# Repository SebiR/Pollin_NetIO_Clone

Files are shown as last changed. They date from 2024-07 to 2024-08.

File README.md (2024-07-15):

# Pollin NetIO Clone
> [!WARNING]  
> The original design is flawed in many ways. If you want to build this design, you should be prepared for some disappointment!
> If you know what you're doing, go ahead. Otherwise you might want to wait for the improved version.

This is a clone of the original Pollin NetIO board.

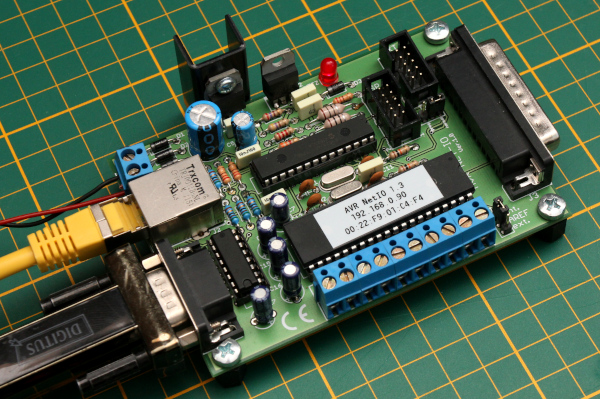
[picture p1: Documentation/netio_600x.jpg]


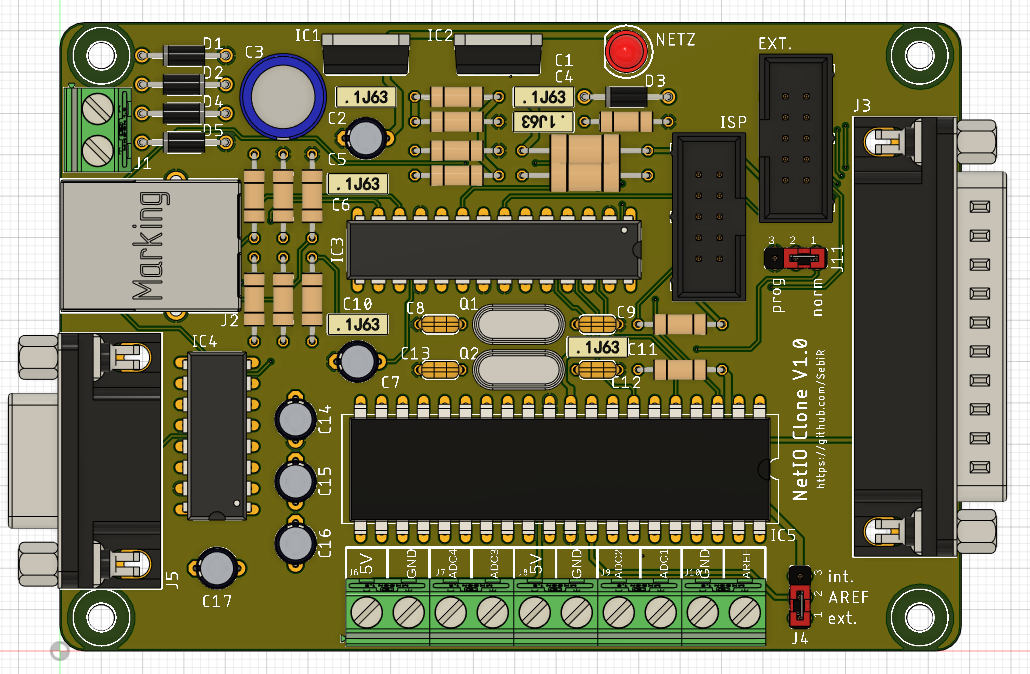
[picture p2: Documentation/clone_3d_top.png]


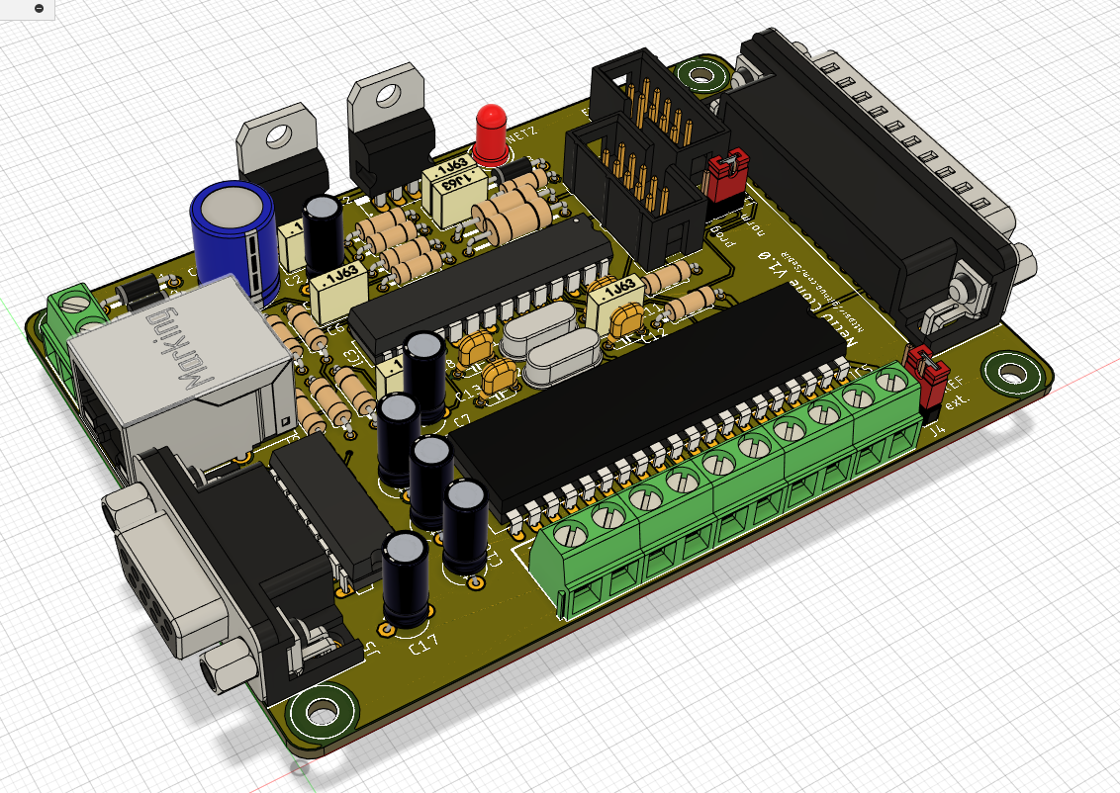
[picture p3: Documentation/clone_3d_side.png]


## Versions
### Original

* As identical as possible to the original
* outline and placement of the components as close as possible
* Assembly plan of the original works

### Improved (tbd)
* Mechanical identical
* Added capacitors and diodes for stability
* placement of the components as close to the original as possible

Things to improve:
* ATmega32 to 3V3? -> Consider compability of extensions
* More capacitors for the ENC28J60
* Diode + capacitors for the LM317
* Connect RS232 handshake lines -> Arduino bootloader compatible

## Software
The original Pollin Netserver 1.03 (provided on a CD) is in /Software/Netserver.zip

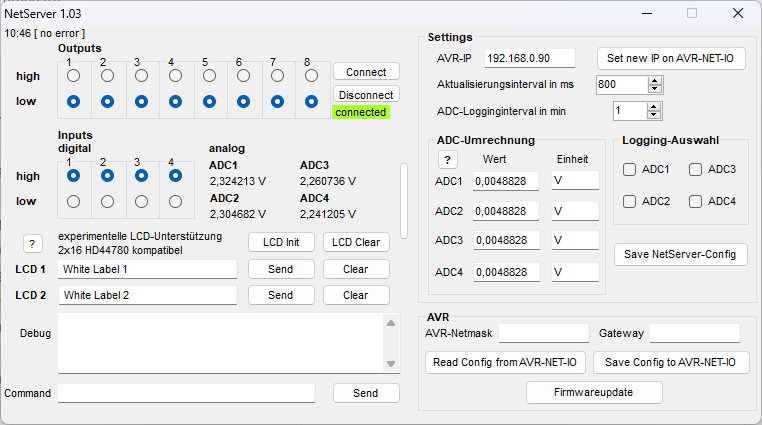
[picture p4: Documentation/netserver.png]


It works just fine with Windows 11.

## Firmware
The original firmware is included.

The MAC address is stored in the EEPROM and can be modified in the .eep file:


So this is MAC address 00:22:F9:01:C4:F4

## Resources
EEPROM Structure: https://www.mikrocontroller.net/topic/112937#1016995

Hardware improvements: https://community.symcon.de/t/p-llins-avr-net-io-langzeitstabilitaet-des-lan-chips/24317/12

General: https://www.mikrocontroller.net/articles/AVR_Net-IO_Bausatz_von_Pollin

## Disclaimer
> [!CAUTION]
> This project was created to archive and preserve the NetIO PCB. Pollin owns all the rights to this design.
> There's no copyright infringement intended, please contact me for removal.

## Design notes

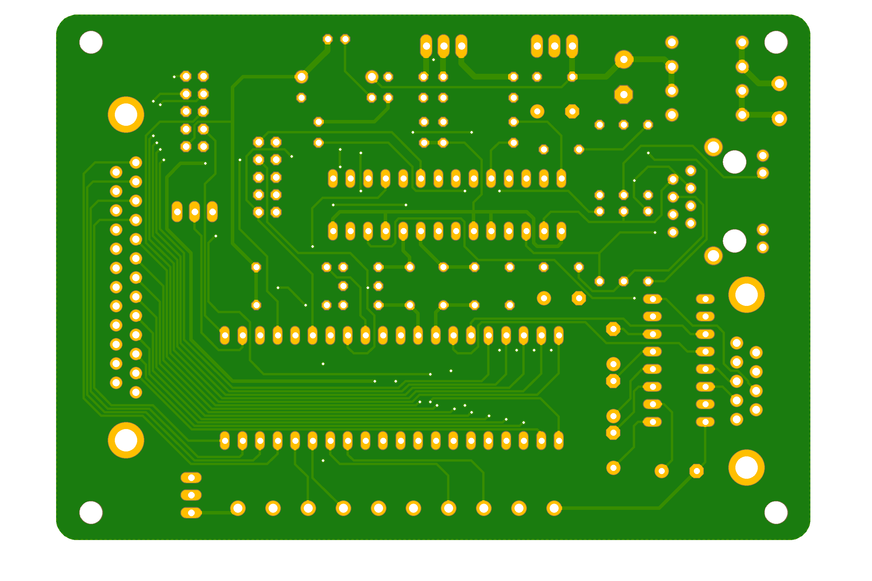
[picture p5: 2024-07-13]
Documentation/Pollin_NetIO_Clone_bot.png

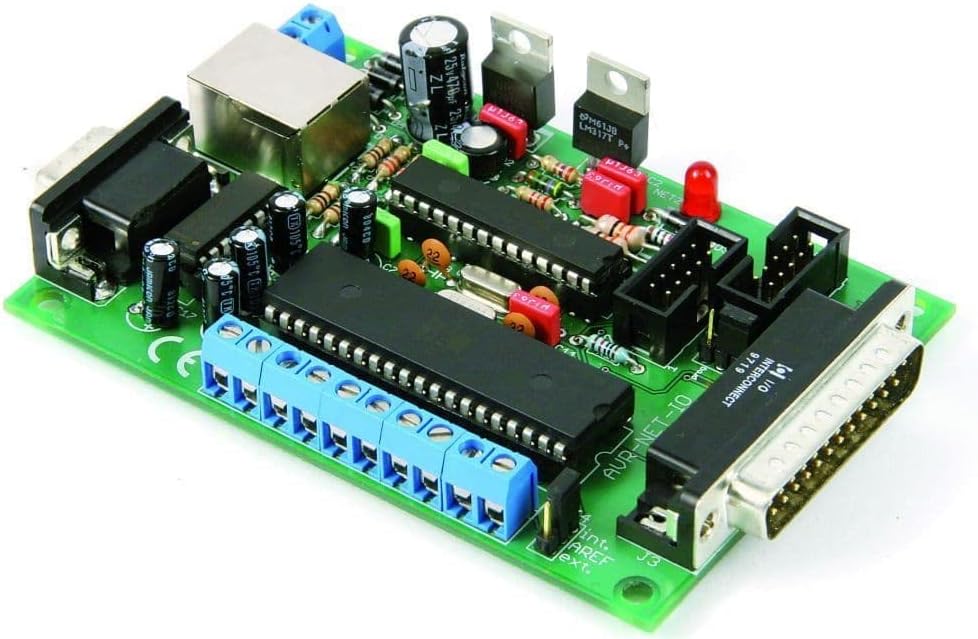
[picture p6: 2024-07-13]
Documentation/netio_original.jpg

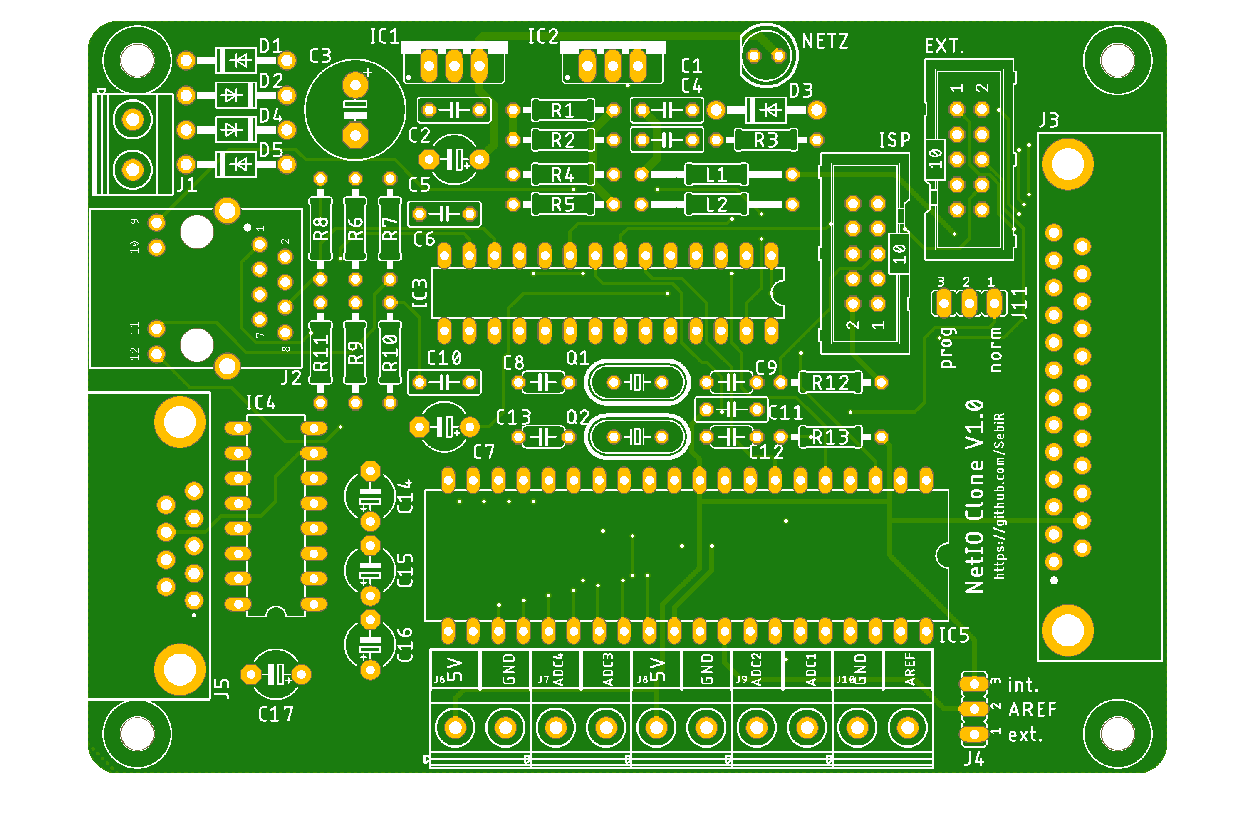
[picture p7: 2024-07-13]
Documentation/Pollin_NetIO_Clone_top.png

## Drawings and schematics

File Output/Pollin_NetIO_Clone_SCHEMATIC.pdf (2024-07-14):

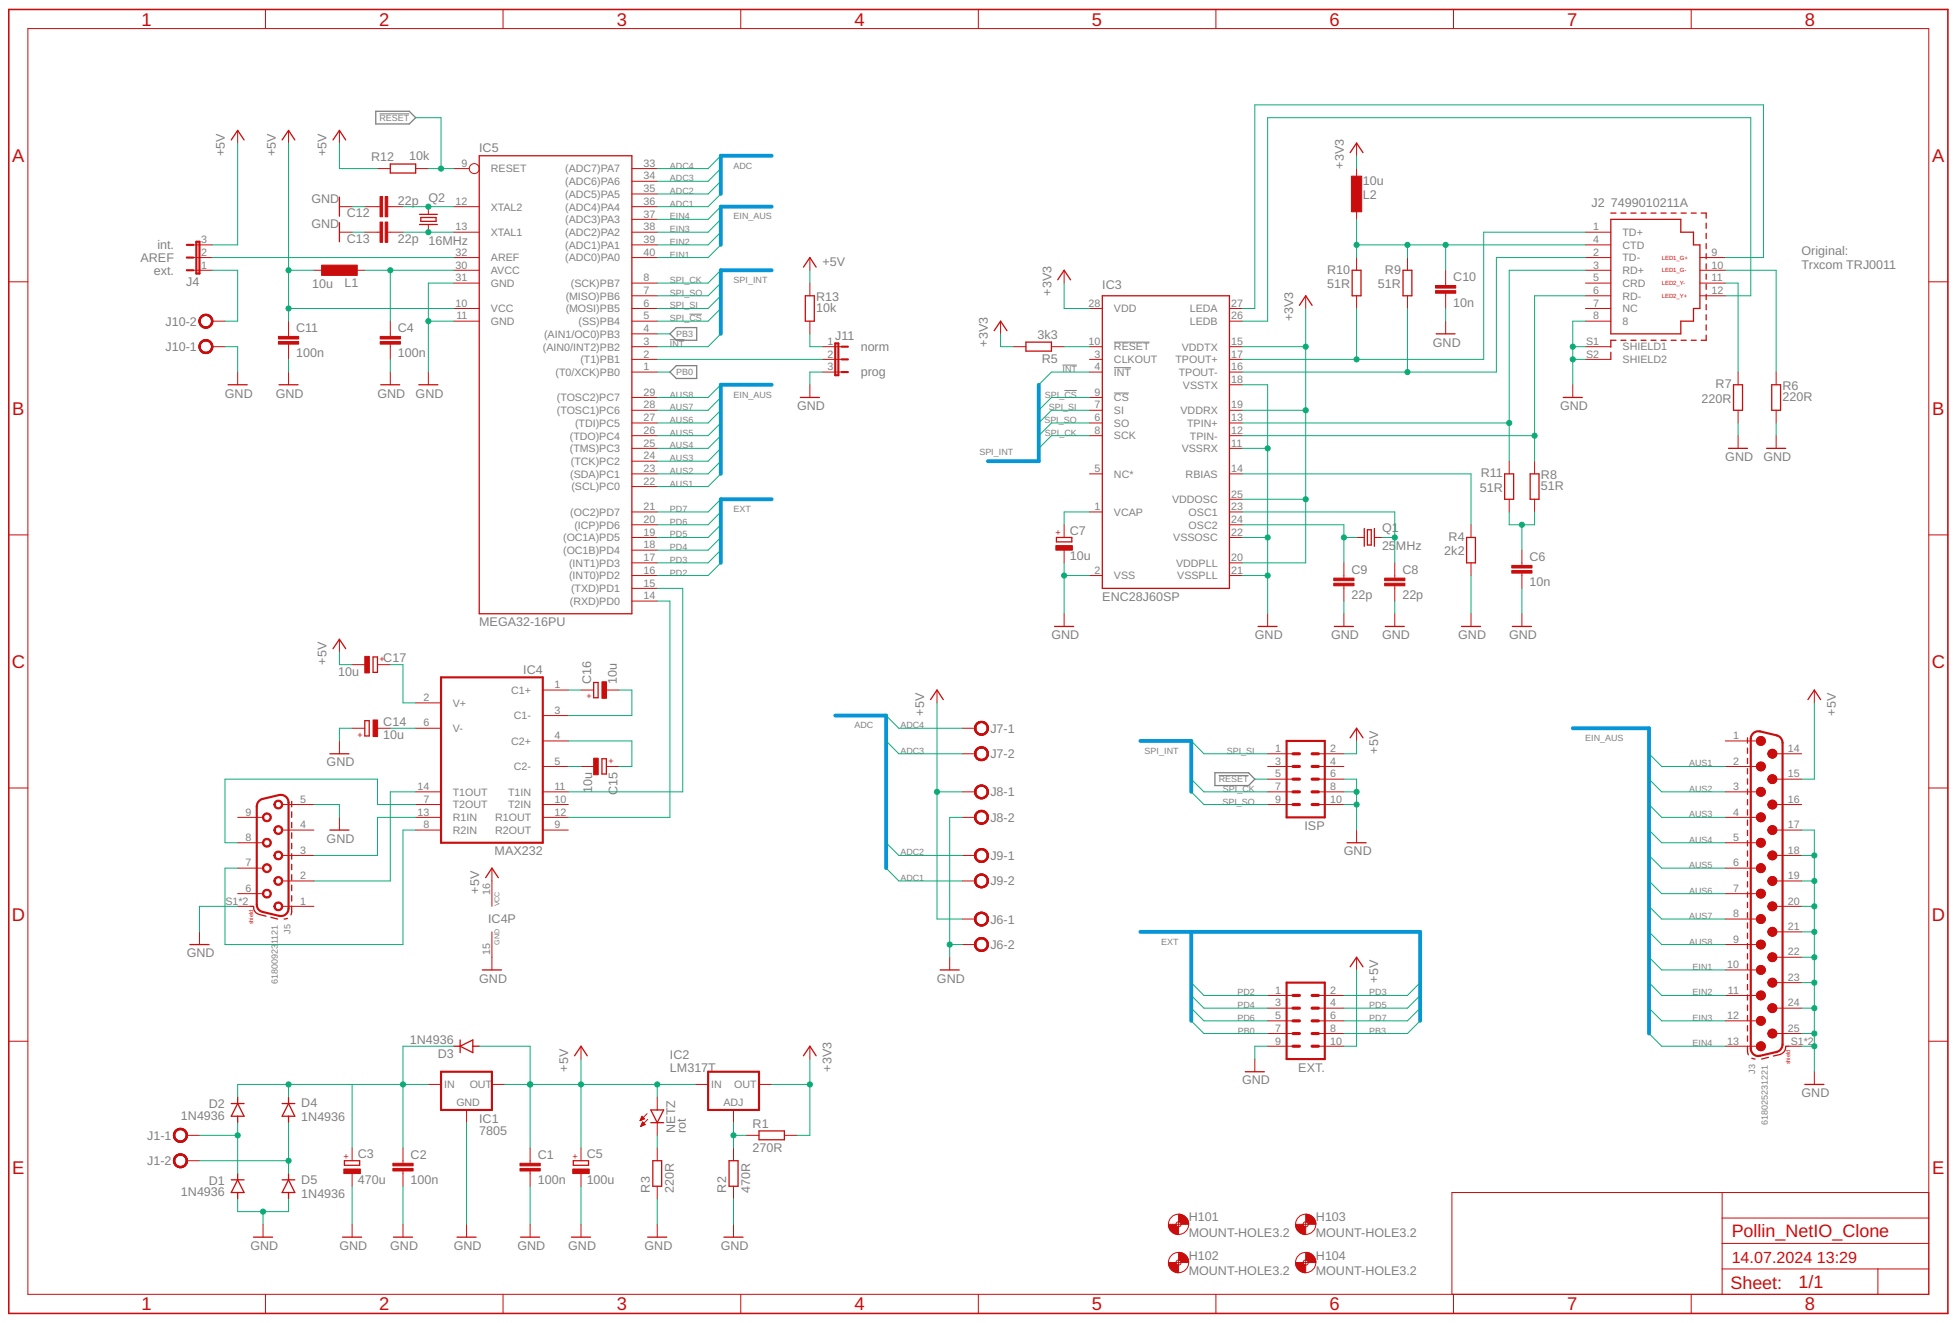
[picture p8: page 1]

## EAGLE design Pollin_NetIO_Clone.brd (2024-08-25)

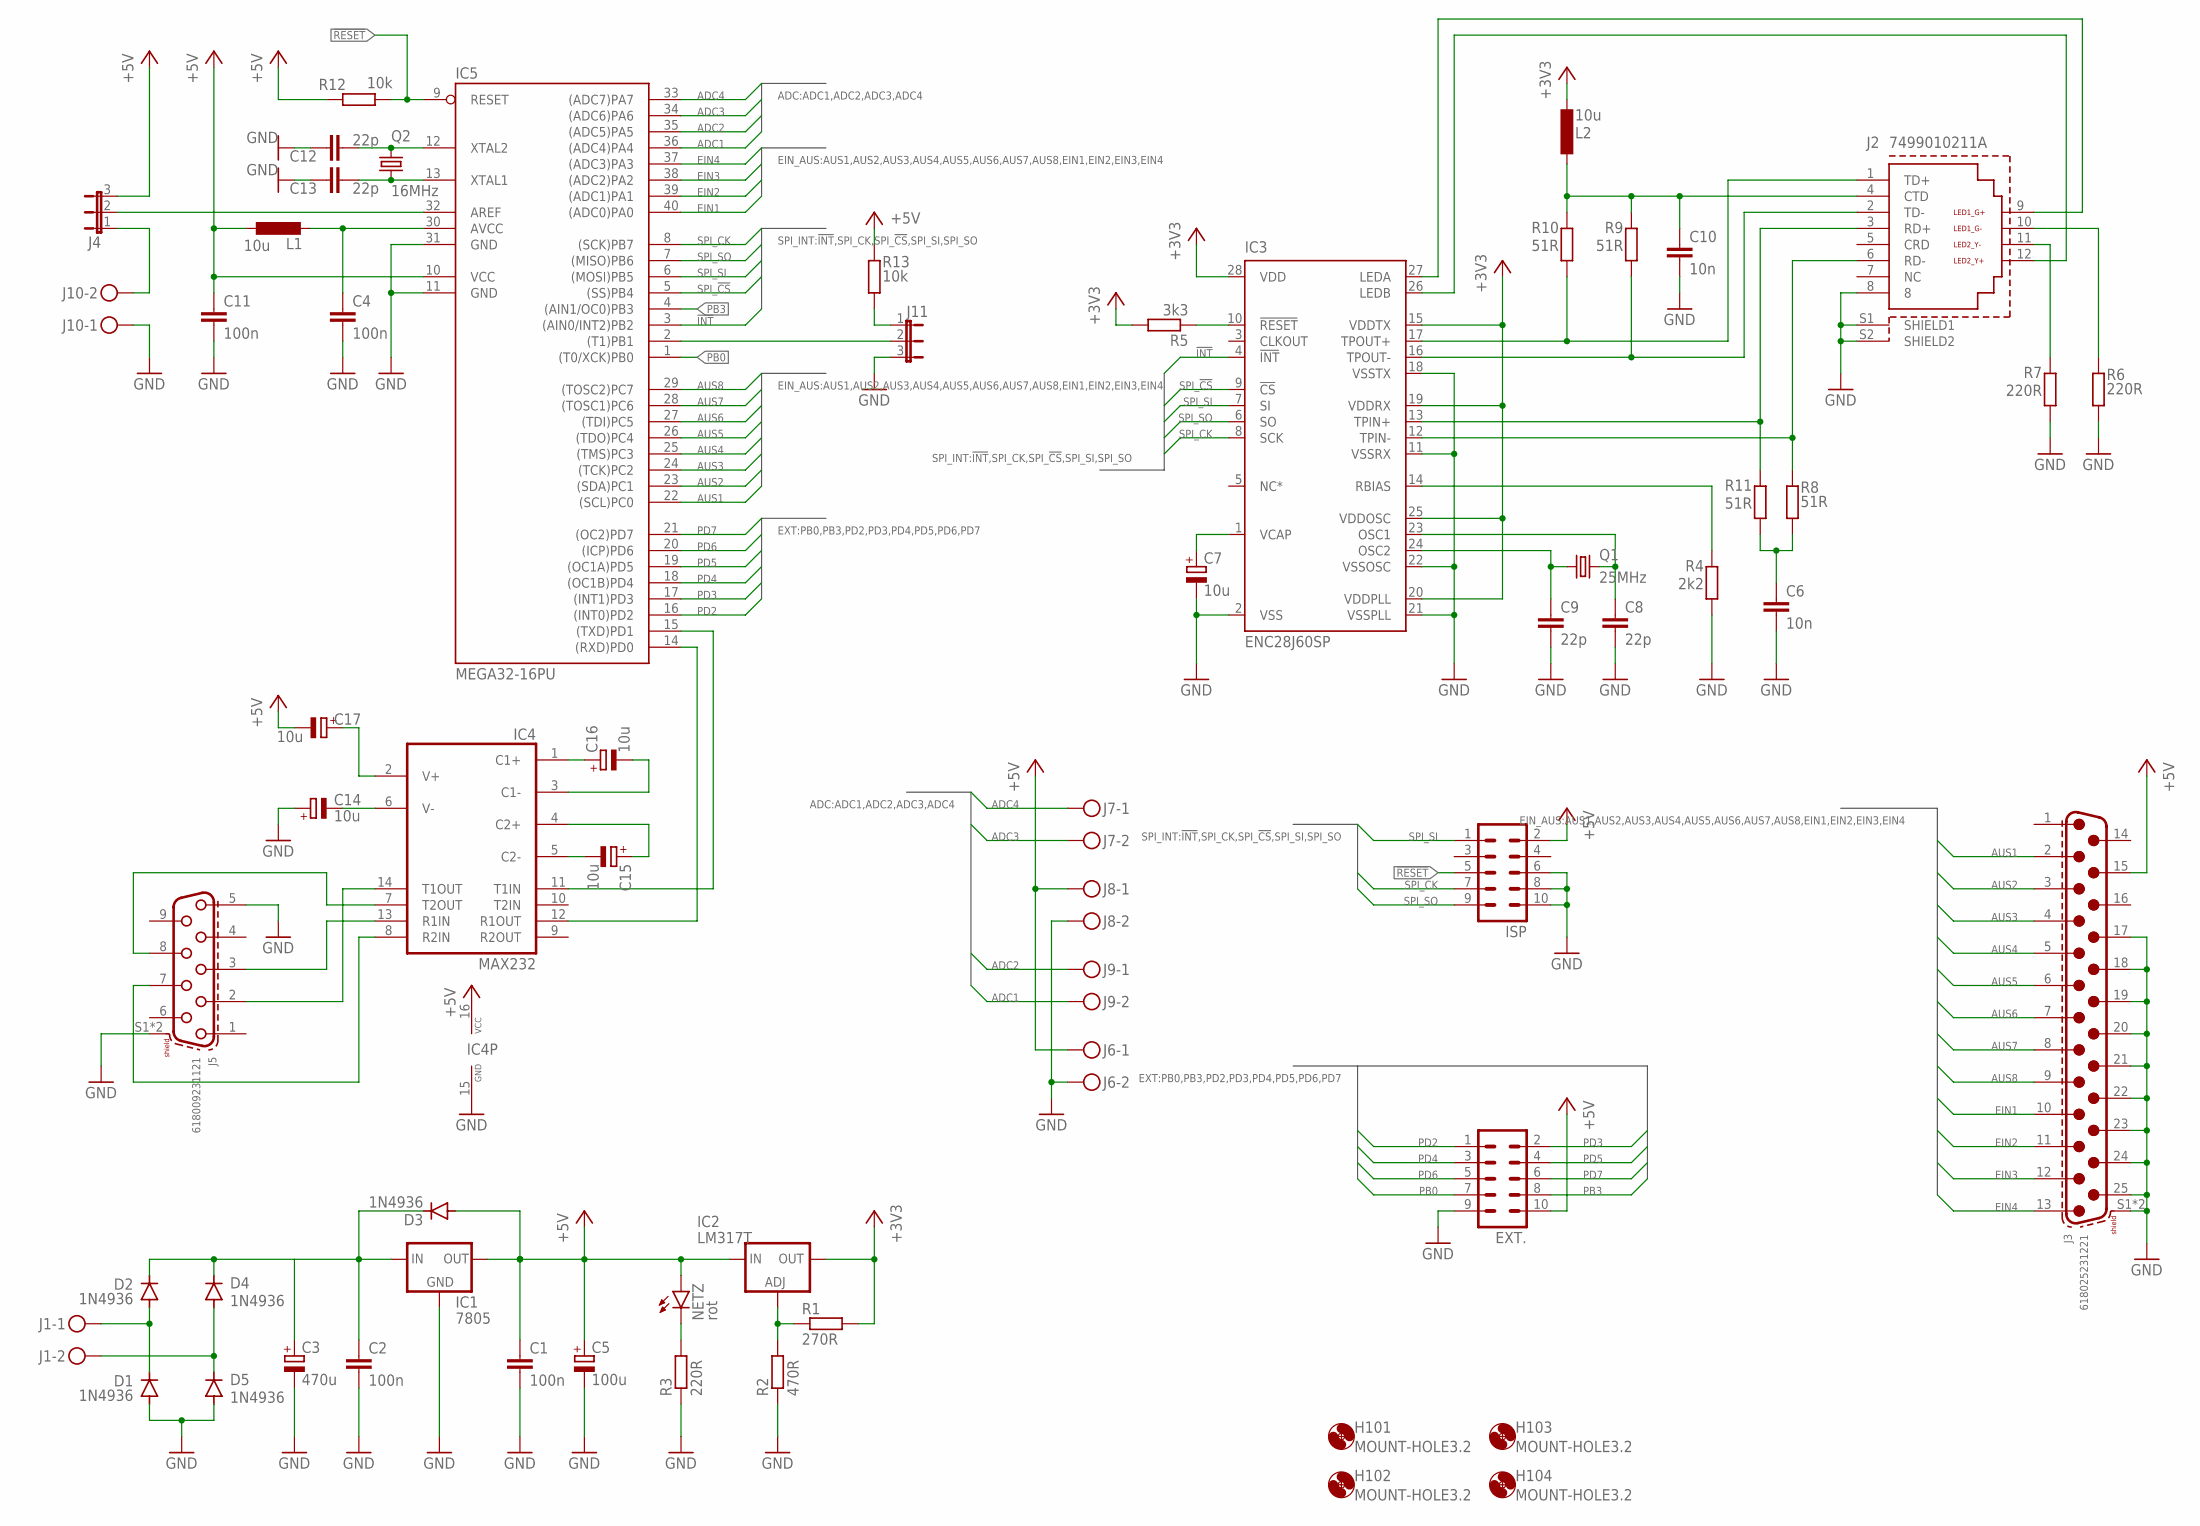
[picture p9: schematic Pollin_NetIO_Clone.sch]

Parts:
C1, C2, C4, C11: 100n; C050-025X075
C3: 470u; E5-10,5
C5: 100u; E5-5
C6, C10: 10n; C050-025X075
C7, C14, C15, C16, C17: 10u; E5-5
C8, C9, C12, C13: 22p; C050-024X044
D1, D2, D3, D4, D5: 1N4936; DO41-10
EXT.: ML10
H101, H102, H103, H104: MOUNT-HOLE3.2; 3,2
IC1: 7805; 78XXS
IC2: LM317T; 317TS
IC3: ENC28J60SP; DIL28-3
IC4: MAX232; DIL16
IC5: MEGA32-16PU; DIL40
ISP: ML10
J1, J6, J7, J8, J9, J10: MKDSN1,5/2-5,08
J2: 7499010211A
J3: 618025231221
J4, J11: JP2E; JP2
J5: 618009231121
L1, L2: 10u; 0207/15
NETZ: rot; LED5MM
Q1: 25MHz; HC49/S
Q2: 16MHz; HC49/S
R1: 270R; 0207/10
R2: 470R; 0207/10
R3, R6, R7: 220R; 0207/10
R4: 2k2; 0207/10
R5: 3k3; 0207/10
R8, R9, R10, R11: 51R; 0207/10
R12, R13: 10k; 0207/10

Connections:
!INT: IC3.4 (!INT), IC5.3 ((AIN0/INT2)PB2)
!RESET: IC5.9 (RESET), ISP.5, R12.2
+3V3: IC2.2 (OUT), IC3.15 (VDDTX), IC3.19 (VDDRX), IC3.20 (VDDPLL), IC3.25 (VDDOSC), IC3.28 (VDD), L2.2, R1.2, R5.2
+5V: C1.1, C5.+, C11.1, C17.-, D3.A, EXT..10, IC1.OUT, IC2.3 (IN), IC4.16 (VCC), IC5.10 (VCC), ISP.2, J3.15, J4.3, J6.1, J8.1, L1.1, NETZ.A, R12.1, R13.2
ADC1: IC5.36 ((ADC4)PA4), J9.2
ADC2: IC5.35 ((ADC5)PA5), J9.1
ADC3: IC5.34 ((ADC6)PA6), J7.2
ADC4: IC5.33 ((ADC7)PA7), J7.1
AREF: IC5.32 (AREF), J4.2
AREF_EXT: J4.1, J10.2
AUS1: IC5.22 ((SCL)PC0), J3.2
AUS2: IC5.23 ((SDA)PC1), J3.3
AUS3: IC5.24 ((TCK)PC2), J3.4
AUS4: IC5.25 ((TMS)PC3), J3.5
AUS5: IC5.26 ((TDO)PC4), J3.6
AUS6: IC5.27 ((TDI)PC5), J3.7
AUS7: IC5.28 ((TOSC1)PC6), J3.8
AUS8: IC5.29 ((TOSC2)PC7), J3.9
AVCC: C4.1, IC5.30 (AVCC), L1.2
EIN1: IC5.40 ((ADC0)PA0), J3.10
EIN2: IC5.39 ((ADC1)PA1), J3.11
EIN3: IC5.38 ((ADC2)PA2), J3.12
EIN4: IC5.37 ((ADC3)PA3), J3.13
GND: C1.2, C2.2, C3.-, C4.2, C5.-, C6.2, C7.-, C8.2, C9.2, C10.2, C11.2, C12.1, C13.1, C14.+, D1.A, D5.A, EXT..9, IC1.GND, IC3.2 (VSS), IC3.11 (VSSRX), IC3.18 (VSSTX), IC3.21 (VSSPLL), IC3.22 (VSSOSC), IC4.15 (GND), IC5.11 (GND), IC5.31 (GND), ISP.6, ISP.8, ISP.10, J2.8, J2.S1 (SHIELD1), J2.S2 (SHIELD2), J3.17, J3.18, J3.19, J3.20, J3.21, J3.22, J3.23, J3.24, J3.25, J3.S1 (SHIELD), J3.S2 (SHIELD), J5.5, J5.S1 (SHIELD), J5.S2 (SHIELD), J6.2, J8.2, J10.1, J11.3, R2.1, R3.1, R4.1, R6.1, R7.1
LEDA: IC3.27 (LEDA), J2.9 (LED1_G+)
LEDB: IC3.26 (LEDB), J2.12 (LED2_Y+)
unnamed: C12.2, IC5.12 (XTAL2), Q2.2
unnamed: C13.2, IC5.13 (XTAL1), Q2.1
unnamed: IC5.2 ((T1)PB1), J11.2
unnamed: C8.1, IC3.23 (OSC1), Q1.1
unnamed: C9.1, IC3.24 (OSC2), Q1.2
unnamed: D1.C, D2.A, J1.1
unnamed: D4.A, D5.C, J1.2
unnamed: C2.1, C3.+, D2.C, D3.C, D4.C, IC1.IN
unnamed: NETZ.K (C), R3.2
unnamed: IC3.14 (RBIAS), R4.2
unnamed: IC2.1 (ADJ), R1.1, R2.2
unnamed: IC3.10 (!RESET), R5.1
unnamed: IC3.17 (TPOUT+), J2.1 (TD+), R10.1
unnamed: IC3.16 (TPOUT-), J2.2 (TD-), R9.1
unnamed: IC3.13 (TPIN+), J2.3 (RD+), R11.2
unnamed: IC3.12 (TPIN-), J2.6 (RD-), R8.2
unnamed: C10.1, J2.4 (CTD), L2.1, R9.2, R10.2
unnamed: C6.1, R8.1, R11.1
unnamed: J11.1, R13.1
unnamed: C7.+, IC3.1 (VCAP)
unnamed: C16.+, IC4.1 (C1+)
unnamed: C16.-, IC4.3 (C1-)
unnamed: C15.+, IC4.4 (C2+)
unnamed: C15.-, IC4.5 (C2-)
unnamed: C17.+, IC4.2 (V+)
unnamed: C14.-, IC4.6 (V-)
unnamed: IC4.7 (T2OUT), J5.8
unnamed: IC4.8 (R2IN), J5.7
unnamed: IC4.14 (T1OUT), J5.2
unnamed: IC4.13 (R1IN), J5.3
unnamed: J2.11 (LED2_Y-), R7.2
unnamed: J2.10 (LED1_G-), R6.2
PB0: EXT..7, IC5.1 ((T0/XCK)PB0)
PB3: EXT..8, IC5.4 ((AIN1/OC0)PB3)
PD2: EXT..1, IC5.16 ((INT0)PD2)
PD3: EXT..2, IC5.17 ((INT1)PD3)
PD4: EXT..3, IC5.18 ((OC1B)PD4)
PD5: EXT..4, IC5.19 ((OC1A)PD5)
PD6: EXT..5, IC5.20 ((ICP)PD6)
PD7: EXT..6, IC5.21 ((OC2)PD7)
RXD: IC4.12 (R1OUT), IC5.14 ((RXD)PD0)
SPI_!CS: IC3.9 (!CS), IC5.5 ((SS)PB4)
SPI_CK: IC3.8 (SCK), IC5.8 ((SCK)PB7), ISP.7
SPI_SI: IC3.7 (SI), IC5.6 ((MOSI)PB5), ISP.1
SPI_SO: IC3.6 (SO), IC5.7 ((MISO)PB6), ISP.9
TXD: IC4.11 (T1IN), IC5.15 ((TXD)PD1)

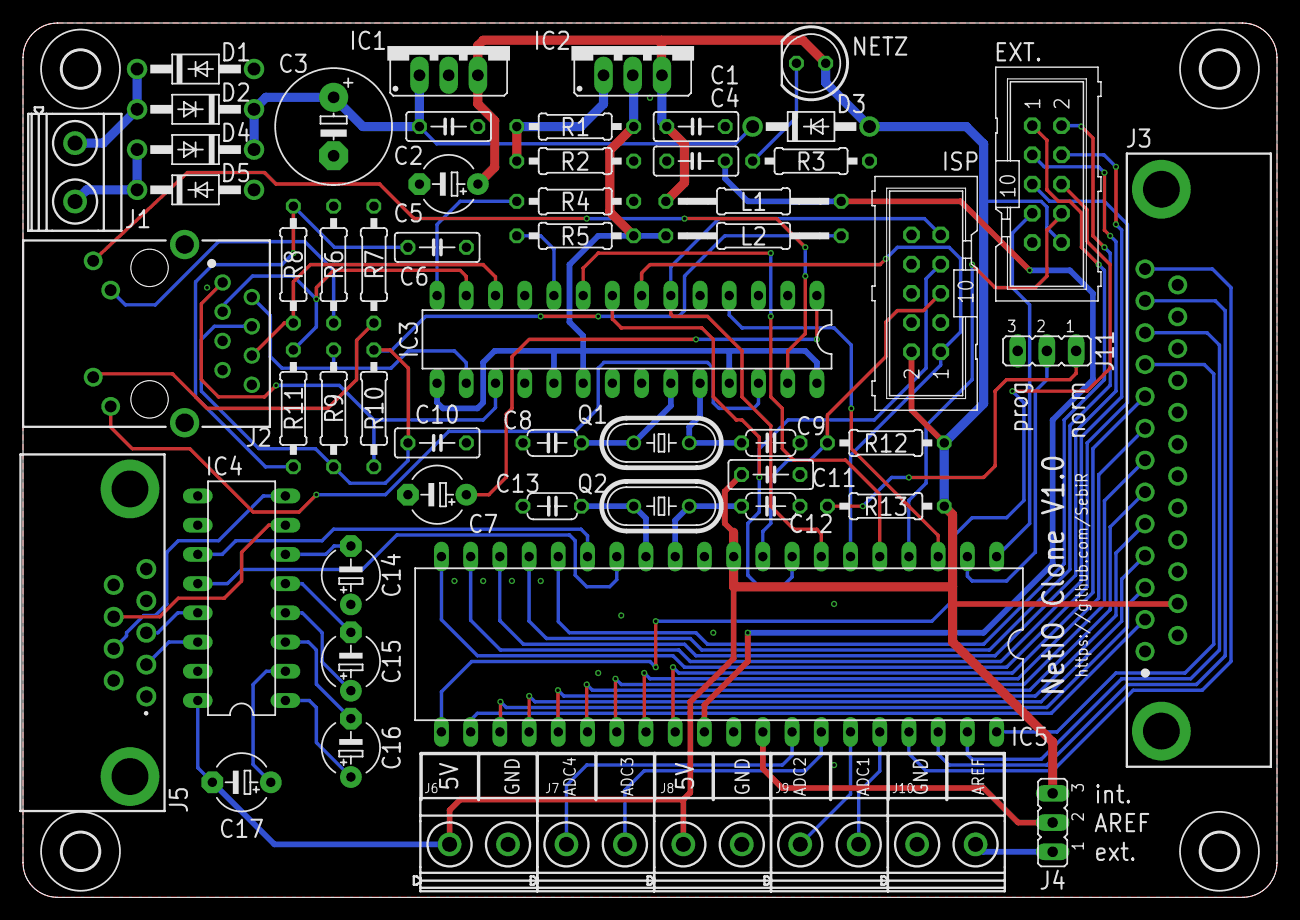
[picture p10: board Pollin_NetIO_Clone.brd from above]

Board: 2 copper layers, 109.0 x 76.0 mm, 62 parts (0 on the bottom side), 72 nets.

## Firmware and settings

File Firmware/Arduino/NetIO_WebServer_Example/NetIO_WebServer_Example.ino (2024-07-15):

/*
Simple Webserver for the Pollin NetIO to display the analog values.

Based on the WebServer Example provided with Arduino

Board needed for the Mega32:
https://github.com/UIPEthernet/UIPEthernet

Library needed for ethernet:
https://www.arduino.cc/reference/en/libraries/uipethernet/
*/

#include <SPI.h>
#include <UIPEthernet.h>

// Enter a MAC address and IP address for your controller below.
// The IP address will be dependent on your local network:
byte mac[] = {
  0xDE, 0xAD, 0xBE, 0xEF, 0xFE, 0xED
};
IPAddress ip(192, 168, 0, 177);

// Initialize the Ethernet server library
// with the IP address and port you want to use
// (port 80 is default for HTTP):
EthernetServer server(80);

void setup() {

  Ethernet.init(4); // PB4 for the Pollin NetIO

  // Open serial communications and wait for port to open:
  Serial.begin(9600);
  while (!Serial) {
    ; // wait for serial port to connect. Needed for native USB port only
  }
  Serial.println("Ethernet WebServer Example");

  // start the Ethernet connection and the server:
  Ethernet.begin(mac, ip);

  // Check for Ethernet hardware present
  if (Ethernet.hardwareStatus() == EthernetNoHardware) {
    Serial.println("Ethernet shield was not found.  Sorry, can't run without hardware. :(");
    while (true) {
      delay(1); // do nothing, no point running without Ethernet hardware
    }
  }
  if (Ethernet.linkStatus() == LinkOFF) {
    Serial.println("Ethernet cable is not connected.");
  }

  // start the server
  server.begin();
  Serial.print("server is at ");
  Serial.println(Ethernet.localIP());
}


void loop() {
  // listen for incoming clients
  EthernetClient client = server.available();
  if (client) {
    Serial.println("new client");
    // an HTTP request ends with a blank line
    bool currentLineIsBlank = true;
    while (client.connected()) {
      if (client.available()) {
        char c = client.read();
        Serial.write(c);
        // if you've gotten to the end of the line (received a newline
        // character) and the line is blank, the HTTP request has ended,
        // so you can send a reply
        if (c == '\n' && currentLineIsBlank) {
          // send a standard HTTP response header
          client.println("HTTP/1.1 200 OK");
          client.println("Content-Type: text/html");
          client.println("Connection: close");  // the connection will be closed after completion of the response
          client.println("Refresh: 5");  // refresh the page automatically every 5 sec
          client.println();
          client.println("<!DOCTYPE HTML>");
          client.println("<html>");
          // output the value of each analog input pin
          for (int analogChannel = 4; analogChannel < 8; analogChannel++) {
            int sensorReading = analogRead(analogChannel);
            client.print("analog input ");
            client.print(analogChannel-3); // Offset to be the same with the NetIO naming convention
            client.print(" is ");
            client.print(sensorReading);
            client.println("<br />");
          }
          client.println("</html>");
          break;
        }
        if (c == '\n') {
          // you're starting a new line
          currentLineIsBlank = true;
        } else if (c != '\r') {
          // you've gotten a character on the current line
          currentLineIsBlank = false;
        }
      }
    }
    // give the web browser time to receive the data
    delay(1);
    // close the connection:
    client.stop();
    Serial.println("client disconnected");
  }
}

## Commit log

2024-07-13 initial commit of original version
    [Pollin_NetIO_Clone.brd, Pollin_NetIO_Clone.sch]
2024-07-13 Added schematic Output/Pollin_NetIO_Clone_SCHEMATIC.pdf
2024-07-13 * cleanded up schematic * changed RJ45 connector to something compatible with the original one
    [Pollin_NetIO_Clone.brd, Pollin_NetIO_Clone.sch]
2024-07-14 * Minor Changes in SCH and BRD * Added original Firmware and EEPROM file * Added STEP model
    [Pollin_NetIO_Clone.brd, Pollin_NetIO_Clone.sch]
2024-07-14 * Updated schematic pdf * Added gerber files
2024-07-15 * Added simple arduino test sketch
2024-07-15 * Fixed fuse settings * Changed eep file to default IP
2024-07-15 small changes
    [Pollin_NetIO_Clone.brd]
2024-08-25 Small Updates in the Layout
    [Pollin_NetIO_Clone.brd]

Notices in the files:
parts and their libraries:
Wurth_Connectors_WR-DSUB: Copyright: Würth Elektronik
